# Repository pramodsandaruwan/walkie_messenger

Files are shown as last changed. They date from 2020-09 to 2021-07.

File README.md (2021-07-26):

# Walkie Messenger

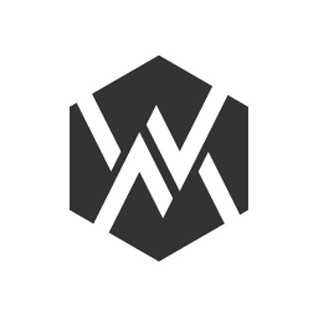
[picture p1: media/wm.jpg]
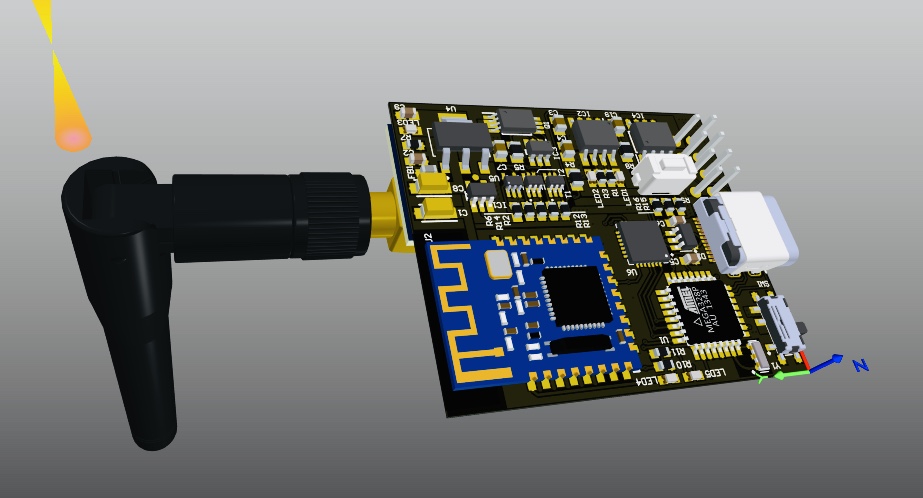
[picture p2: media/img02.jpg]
 

#### Title: Wireless Short-Range Communication Device (Walkie Messenger)
#### Introduction
A regular problem that can occur in hiking groups is that the group can easily spread out as the hike progresses. Some of your party will get chatting, some will stop to take photos, some are faster over rocky terrain or rock scrambles, some are simply fitter than others and can maintain a faster pace. Inevitably, a gap between the lead and whip of your group opens up and the main role of the group leader is to make sure that the gap doesn’t get so wide as to become unmanageable to the point where one part of the group can’t locate the other. Walkie Messenger is a solution for the above problem. It provides messaging, locating, tracking so you can stay connected to your group, whenever you're outside of cellular range. In case of a life-threatening emergency, the device can contact search & rescue services. (SOS function). This device comes with a mobile phone app (Android and IOS), so you can easily message your group members, send your GPS location, can track the friend’s location. In case of Low battery in your mobile, the device automatically sends your last location to all group members. In the SOS function, the device sends your GPS location to group members. if you are in cellular range, the device sends the location to search & rescue services through SMS. If not trying to send SMS through group members' mobile.

#### Product Description
##### Specifications

  - Wireless ranges
    - Wireless transmit and receive maximum range 1100m. (2.4GHz)
    - Bluetooth 5.0 with maximum range up to 100m.
    - Compatible with Bluetooth 4.2 and 4.0 devices.
  - Body
    - Dimensions 50(L) x 40(W) x 10(H) mm
    - Weight 180g
  - storage information
    - Work with mobile phone storage.
    - Device memory 32Kb (EEPROM).
  - Power
    - 2000mAH Li-Ion rechargeable nonremovable battery (3.7V).
    - Operating at 3.3V
    - Sleep mode while in standby
  - Charging
    - Recommended 1.5A USB charger for fast charging.
    
#### Functions
  - Control using mobile phone App.
  - Person to Person chat (Peer to peer communication).
  - Group chat capability (Mesh networking).
  - End to end encryption to chat.
  - Adjustable maximum transmitting range for power saving.
  - SOS button in the device to inform near persons in case of an emergency.
  - Low battery warning.
  - Firmware update over USB.
  - Automatic charging current controlling to match the power supply capability.
  - USB Type C reversible charging connector with charging current up to 1.2A.
  
#### Limitations
  - Battery life.
  - Wireless Transmitting range.
  - GPS coverage
  
#### Methodology
Walkie messenger used NRF24L01+ Single chip 2.4GHz Transceiver communicate between walkie devices (Maximum distance up to 1100m) and Bluetooth 5.0 used to connect to smart mobile phone (Maximum distance up to 100m). Some modern mobile phone has Bluetooth 4.0 or 4.2, So walkie can connect to these devices with maximum range 60m.

The amplifier IC and 20dB Antenna is used to increase the wireless communication Range. Bluetooth module has in-built PCB antenna. Atmega 328p 8bit microcontroller is used as controller.Microcontroller used UART (Universal Asynchronous Receiver/Transmitter) communication protocol to communicate with Bluetooth module and SPI (Serial peripheral interface) used to communicate between NRF24L01+ chip. 

The test message type and send to device using mobile phone application over Bluetooth. The GPS coordinates and mobile phone battery stats send to device automatically. NRF24L01+ chip has three power modes, so it can be configured using mobile app.

The CP2102n USB to Serial converter IC is used to connect device to USB interface. Firmware upgrading can do over USB (PC or MAC) and Bluetooth. Li-ion 300mAh is used to power the device, it works between the voltage level of 3.7v-4.2v and a BMS (Battery management system) is used to maintain battery health. A DC-DC converter is used to bring the voltage to 3.3V to power the Atmega 328p microcontroller and Communicating modules.

<center>
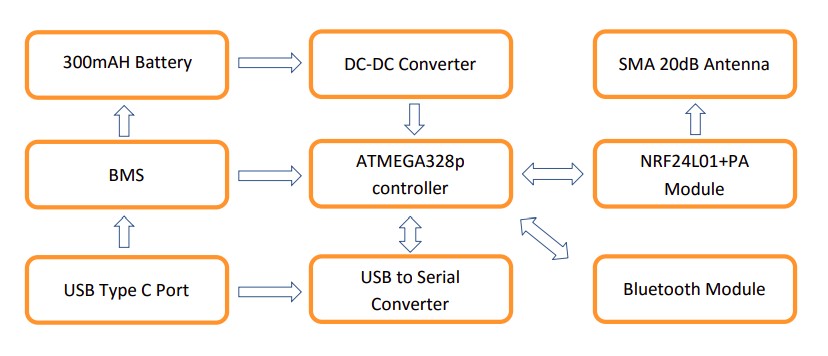
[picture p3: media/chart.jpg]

</center>

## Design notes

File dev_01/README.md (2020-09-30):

#### Walkie Messenger device 01 ( MINI version )

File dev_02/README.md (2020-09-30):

#### Walkie Messenger device 02 

##### Additional Specifications compared with WM mini 
- LCD display
- High Gain Antenna
- 2000mAH Li-ion Battery

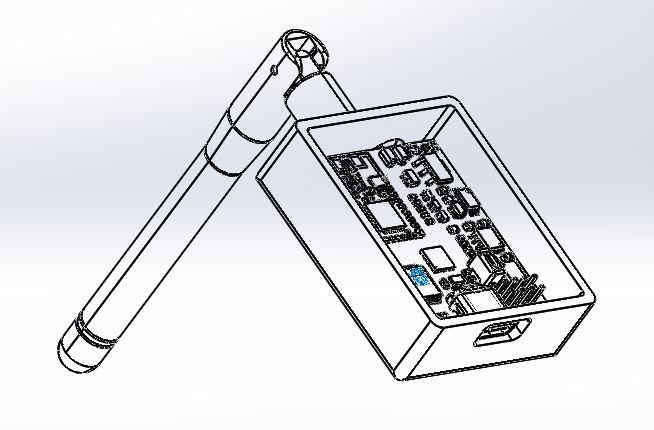
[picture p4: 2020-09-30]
media/Capture.JPG

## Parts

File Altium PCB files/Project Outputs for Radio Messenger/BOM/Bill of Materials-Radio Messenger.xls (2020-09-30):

Line # | Designator | value | Name | Description | Quantity | Manufacturer 1 | Manufacturer Part Number 1 | Manufacturer Lifecycle 1 | Supplier 1 | Supplier Part Number 1 | Supplier Unit Price 1 | Supplier Subtotal 1
 | C1, C8 | 10uF | tantalum capacitor 1206 | Capacitor Polarised | 2
 | C2, C5, C6, C9 | 0.1uF | capacitor 0603 | Capacitor | 4
 | C3, C4 | 10uF | 08055A101JAT2A | Capacitor | 2
 | C7 | 0.1uF | 08055A101JAT2A | Capacitor | 1
 | C19 | 4.7uF | 08055A101JAT2A | Capacitor | 1
 | D1 |  | USBLC6-2SC6 | USBLC6 Series 2 Line 6 V Uni / Bi-Directional ESD Protection - SOT-23-6 | 1
 | FB1 | 10uH | inductor 0603 | Ferrite Bead | 1
 | IC1 |  | TPS62203 | Integrated Circuit | 1
 | IC2 |  | TP4056 | Integrated Circuit | 1
 | IC3 |  | DW01-P | Integrated Circuit | 1
 | IC4 |  | SI4143DY-T1-GE3 | Integrated Circuit | 1
 | J1 |  | DX07S024XJ1R1100 | Cut Tape - Usb Type c Receptacle Mid Mnt Dual r | 1
 | J2 |  | S2B-ZR-SM4A-TF(LF)(SN) | Connector Header Surface Mount, Right Angle 2 position 0.059 _1.50mm_ | 1
 | LED1, LED4 | Red | HSMR-C191 | LED Indication - Discrete 3.4V 0603 _1608 Metric_ | 2
 | LED2, LED3 | Green | HSMR-C191 | LED Indication - Discrete 3.4V 0603 _1608 Metric_ | 2
 | LED5 | Orange | HSMR-C191 | LED Indication - Discrete 3.4V 0603 _1608 Metric_ | 1
 | Q1 |  | FS8205A | Transistor | 1
 | R1, R3, R7, R10, R11 | 1K | resistor | Resistor | 5
 | R2 | 1.2K | resistor | Resistor | 1
 | R4 | 100 | CPF0805 | Resistor | 1
 | R5 | 1K | CPF0805 | Resistor | 1
 | R6 | 470K | resistor | Resistor | 1
 | R8 | 10K | CPF0805 | Resistor | 1
 | R9, R12, R13 | 10K | resistor | Resistor | 3
 | R14 | 2K | resistor | Resistor | 1
 | R15 | 22.1K | resistor | Resistor | 1
 | R16 | 47.5K | resistor | Resistor | 1
 | S1 |  | PTS810SJK250SMTRLFS | Tactile Switch SPST-NO Top Actuated Surface Mount | 1
 | SW1 |  | 1437575-1 | Slide Switch SPDT Surface Mount, Right Angle | 1
 | T1, T2 |  | PMGD780SN | Mosfet Array 2 N-Channel _Dual_ 20V 1.2A 390mW Surface Mount 6-TSSOP | 2 | Philips | PMGD780SN,115 | Volume Production | Digi-Key | 1727-3127-1-ND | 0.42 | 0.84
 | U1 |  | ATMEGA328P-AN | AVR AVRÂ® ATmega Microcontroller IC 8-Bit 20MHz 32KB _16K x 16_ FLASH 32-TQFP _7x7_ | 1 | Microchip / Atmel | ATMEGA328P-ANR | Volume Production | Digi-Key | ATMEGA328P-ANRCT-ND | 2.18 | 2.18
 | U2 |  | JDY-23 | Bluetooth Bluetooth v4.0 Transceiver Module 2.4GHz Integrated, Chip Surface Mount | 1
 | U3 |  | NRF24L01P+ |  | 1
 | U4 |  | AMS1117 | 1A LOW DROPOUT VOLTAGE REGULATOR | 1 | STMicroelectronics | LD1117STR | Volume Production | Digi-Key | 497-1244-1-ND | 0.43 | 0.43
 | U5 |  | LMS33460MG | 3V Under Voltage Detector 5-SC70 -40 to 85 | 1
 | U6 |  | CP2102N-A01-GQFN28 | USB Bridge, USB to UART USB 2.0 UART Interface 28-QFN _5x5_ | 1
 | Y1 |  | PBRC8.00MR10X000 | 8MHz Ceramic Resonator Built in Capacitor 15pF Â±0.1% -40Â°C ~ 85Â°C Surface Mount | 1

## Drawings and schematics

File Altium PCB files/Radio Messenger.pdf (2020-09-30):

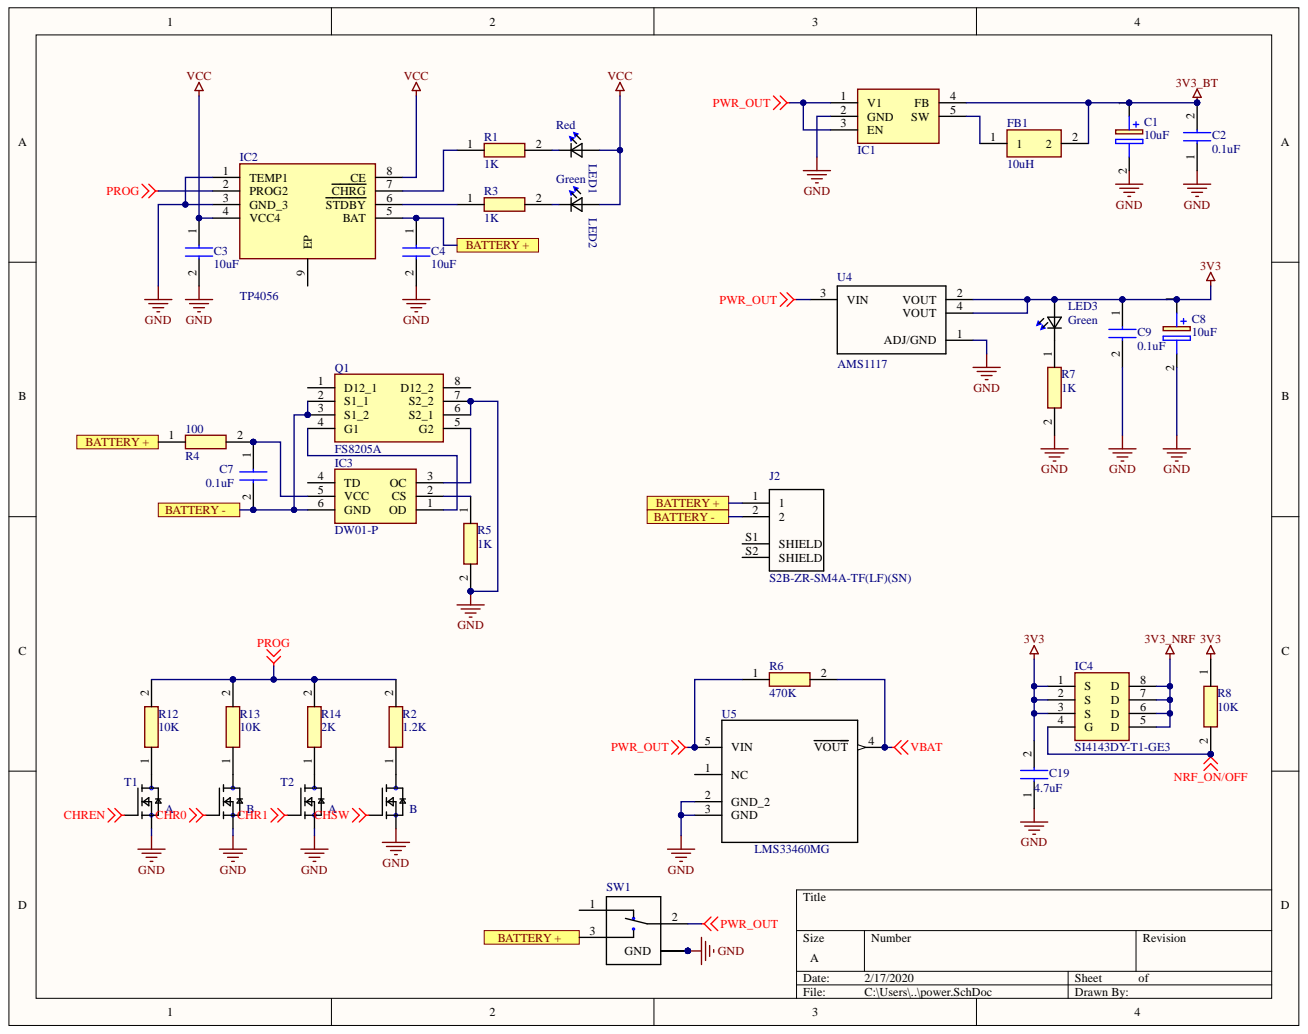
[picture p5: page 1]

PROG2 2

VCC4 4

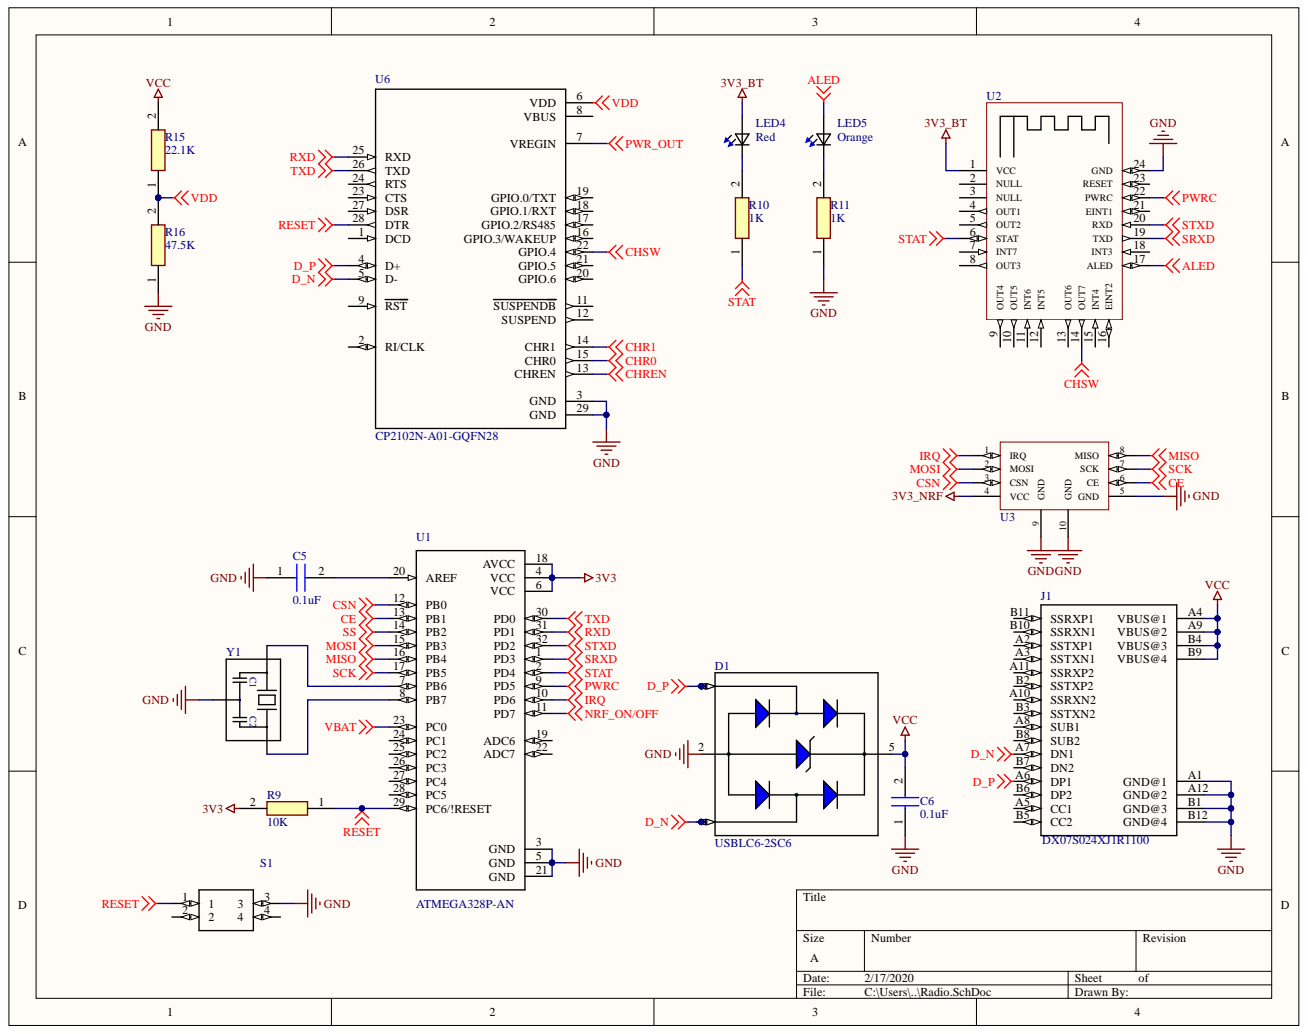
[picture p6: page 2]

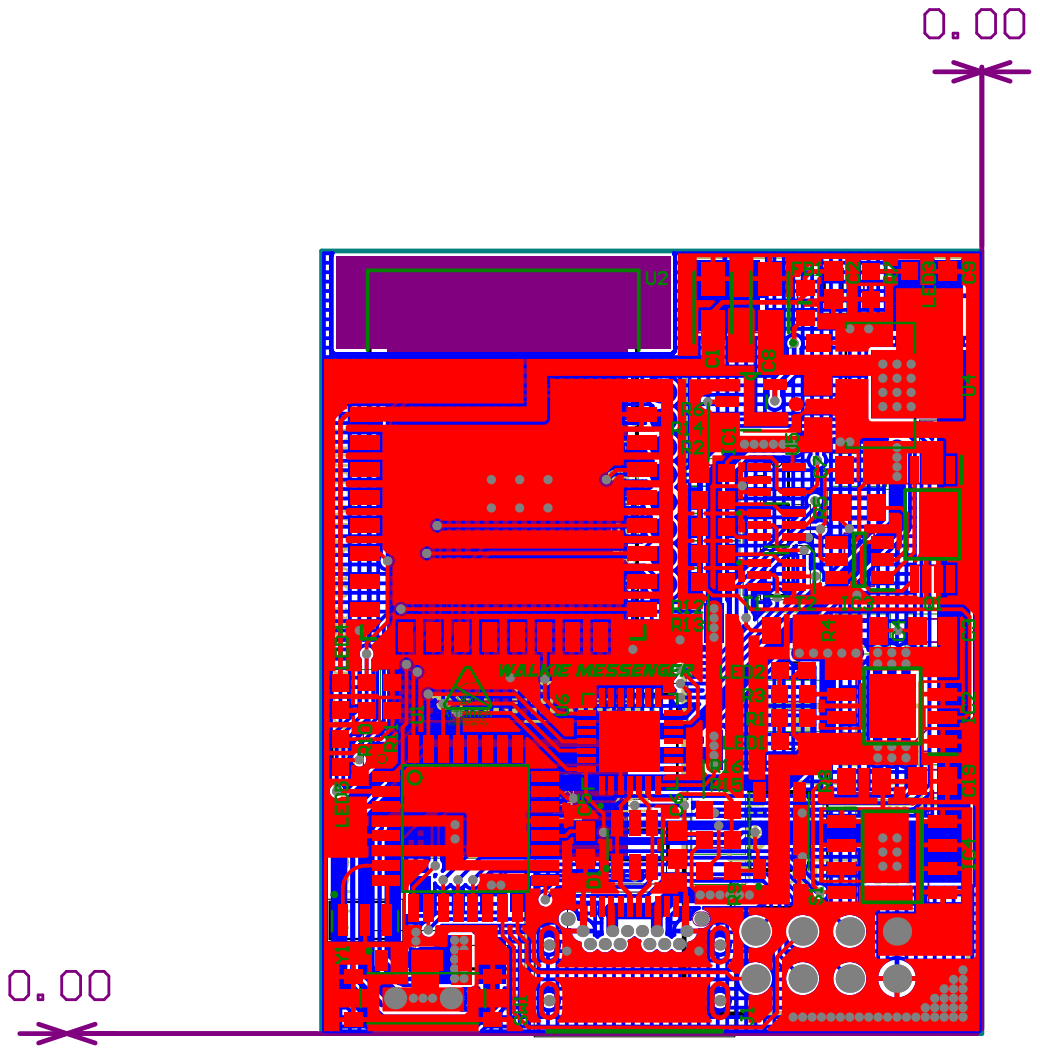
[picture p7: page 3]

Line # | Designator | value | Name | Description | Quantity | Footprint | Manufacturer 1 | Manufacturer PartNumber 1 | Manufacturer Lifecycle 1 | Supplier 1 | Supplier PartNumber 1 | Supplier UnitPrice 1 | Supplier Subtotal 1
| C1,C8 | 10uF | tantalum capacitor 1206 | Capacitor Polarised | 2 | CAPPM3216X180N | KEMET | T491A106K010AT | Volume Production | Digi-Key | 399-3684-1-ND | 0.41 | 0.82
| C2,C5,C6,C9 | 0.1uF | capacitor 0603 | Capacitor | 4 | *CAPC1608X95N | KEMET | C0603C104K5RACTU | Volume Production | Digi-Key | 399-5089-1-ND | 0.12 | 0.48
| C3,C4 | 10uF | 08055A101JAT2A | Capacitor | 2 | CAPC2012X94N | Kyocera AVX | 08055A101JAT2A | Volume Production | Digi-Key | 478-1316-1-ND | 0.16 | 0.32
| C7 | 0.1uF | 08055A101JAT2A | Capacitor | 1 | CAPC2012X94N | Kyocera AVX | 08055A101JAT2A | Volume Production | Digi-Key | 478-1316-1-ND | 0.16 | 0.16
| C19 | 4.7uF | 08055A101JAT2A | Capacitor | 1 | CAPC2012X94N | Kyocera AVX | 08055A101JAT2A | Volume Production | Newark | 60R6300 | 0.018 | 0.018
| D1 | | USBLC6-2SC6 | USBLC6 Series2 Line | 1 | *SOT95P2 80X145-6N
| FB1 | 10uH | inductor 0603 | Ferrite Bead | 1 | BEADC1608X95N
| IC1 | | TPS62203 | Integrated Circuit | 1 | SOT95P280X145-5N
| IC2 | | TP4056 | Integrated Circuit | 1 | SOIC127P600X175-9N
| IC3 | | DW01-P | Integrated Circuit | 1 | SOT95P280X135-6N
| IC4 | | SI4143DY-T1-GE3 | Integrated Circuit | 1 | SI4143DY-T1-GE3
| J1 | | DX07S024XJ1R1100 | CutTape - Usb Type c | 1 | *JAE_DX07 S024XJ1R1100_DX07S024XJ1R1100(Primary)
| J2 | | S2B-ZR-SM4A-TF(LF)(SN) | Connector Header Su | 1 | *JST_S2B-ZR-SM4A-TF(LF)(SN)_S2B-ZR-SM4A-TF(LF)(SN)(Primary)
| LED1, LED4 | Red | HSMR-C191 | LED Indication - Discr | 2 | *0603
| LED2, LED3 | Green | HSMR-C191 | LED Indication - Discr | 2 | *0603
| LED5 | Orange | HSMR-C191 | LED Indication - Discr | 1 | *0603
| Q1 | | FS8205A | Transistor | 1 | SOP65P640X120-8N
| R1,R3,R7,R10,R11 | 1K | resistor | Resistor | 5 | RESC1608X55N
| R2 | 1.2K | resistor | Resistor | 1 | RESC1608X55N
| R4 | 100 | CPF0805 | Resistor | 1 | RESC2012X65N
| R5 | 1K | CPF0805 | Resistor | 1 | RESC2012X65N
| R6 | 470K | resistor | Resistor | 1 | RESC1608X55N
| R8 | 10K | CPF0805 | Resistor | 1 | RESC2012X65N
| R9,R12,R13 | 10K | resistor | Resistor | 3 | RESC1608X55N
| R14 | 2K | resistor | Resistor | 1 | RESC1608X55N
| R15 | 22.1K | resistor | Resistor | 1 | RESC1608X55N
| R16 | 47.5K | resistor | Resistor | 1 | RESC1608X55N
| S1 | | PTS810SJK250SMTRLFS | Tactile Switch SPST-N | 1 | *PTS810SJG250SMTRLFS
| SW1 | | 1437575-1 | Slide Switch SPDTSur | 1 | *SW_MLL1200S_MLL1200S(Primary)
| T1,T2 | | PMGD780SN | MosfetArray2 N-Chan | 2 | *SOP65P210X110-6N | Philips | PMGD780SN,115 | Volume Production | Digi-Key | 1727-3127-1-ND | 0.42 | 0.84
| U1 | | ATMEGA328P-AN | AVRAVRÂ® ATmega M | 1 | *QF P80P900X900X120-32N | Microchip/Atmel | ATMEGA328P-ANR | Volume Production | Digi-Key | ATMEGA328P-ANRCT-ND | 2.18 | 2.18
| U2 | | JDY-23 | Bluetooth Bluetooth v | 1 | *JDY-23
| U3 | | NRF24L01P+ | | 1 | NRF24L01P+
| U4 | | AMS1117 | 1ALOWDROPOUTVOL | 1 | *SOT229P700X180-4N | STMicroelectronicsLD1117STR | | Volume Production | Digi-Key | 497-1244-1-ND | 0.43 | 0.43
| U5 | | LMS33460MG | 3VUnder Voltage Det | 1 | *SOT65P210X110-5N
| U6 | | CP2102N-A01-GQFN28 | USBBridge,USBto UA | 1 | *QFN50P500X500X80-29N
| Y1 | | PBRC8.00MR10X000 | 8MHzCeramicResona | 1 | *XTAL_PBRC8.00MR10X000

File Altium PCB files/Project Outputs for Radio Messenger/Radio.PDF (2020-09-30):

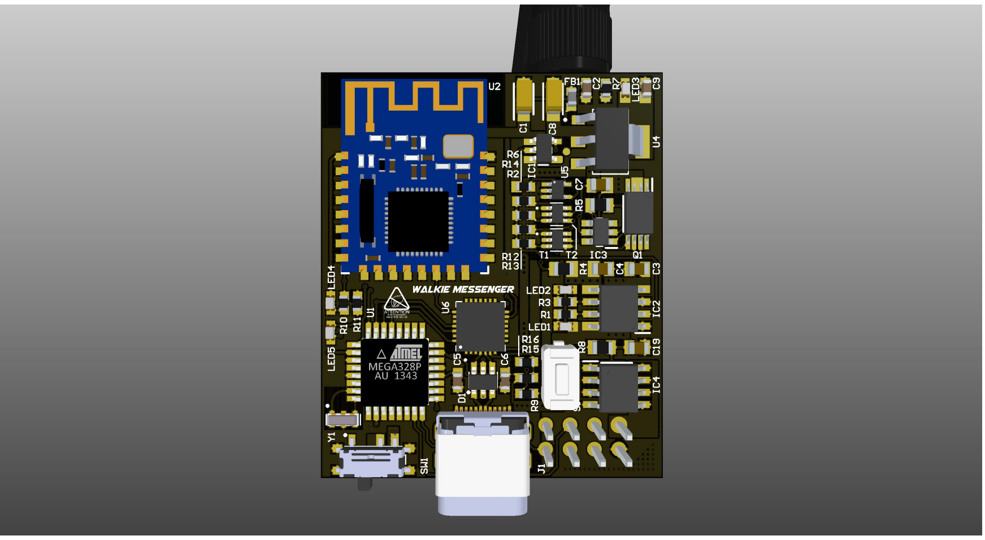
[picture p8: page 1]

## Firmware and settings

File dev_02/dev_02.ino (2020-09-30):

/************************************************************************************************
 * Devoloped by pramod sandaruwan for third year electric product design and manufacture course.
 * Contact: pramodsandaruwan80@gmail.com
 * Elelctrinic and Electronic Engineer
 * Undergraduate, University of peradeniya
************************************************************************************************/

/* Authors: Pramod Sandaruwan */

#include <SoftwareSerial.h>
#include <LiquidCrystal_I2C.h>
#include <string.h>
#include <EEPROM.h>

#include <RF24.h>
#include <RF24Network.h>
#include <SPI.h>

RF24 radio(7, 8);                // nRF24L01 (CE,CSN)
RF24Network network(radio);      // Include the radio in the network
const uint16_t this_node = 01;   // Address of this node in Octal format ( 04,031, etc)
const uint16_t node01 = 00; 

SoftwareSerial BlueTooth(2, 3); // RX, TX
LiquidCrystal_I2C lcd(0x27,20,4);  // set the LCD address to 0x27 for a 16 chars and 2 line display

bool bt_stat = 0;
const int red = 10;
const int grn = 9;
const int pwr = 6;
const int bt_pin = 4;
String a;
String CH_config;

void setup() {
  
  //Serial.begin(38400);
  lcd.init(); 
  pinMode(red, OUTPUT);
  pinMode(grn, OUTPUT);
  pinMode(pwr, OUTPUT);
  pinMode(bt_pin,INPUT);
  boot();                     
  BlueTooth.begin(38400);
  BlueTooth.println("bluetooth test ");
  
  SPI.begin();
  radio.begin();
  radio.setPALevel(RF24_PA_MAX);
  network.begin(EEPROMReadInt(128), this_node);  //(channel, node address)

  lcd.backlight();
  lcd.setCursor(0,0);
  lcd.print("Hello,welcome to");
  lcd.setCursor(0,1);
  lcd.print("Walkie messenger");
  delay(2000);
  lcd.setCursor(0,0);
  lcd.print("                ");
  lcd.setCursor(0,0);
  lcd.print("RF.CH>");
  lcd.setCursor(6,0);
  lcd.print(EEPROMReadInt(128));
  lcd.setCursor(8,0);
  lcd.print("|WM-V1.0");
}

void loop() {
  
  bt_connected();
  network.update();
  char text[] = "Walkie messenger data transfer";
  
  /* Bluetooth to RF */
  if(bt_connected()){
    if (BlueTooth.available() > 0) {
        // read the incoming byte:
        a = BlueTooth.readString();
        
        if (a.substring(0,5) == "setCH"){
          CH_config = a.substring(6,8);
          ch_configure(CH_config.toInt());
          }
        if (a == "getCH"){
          BlueTooth.print("RF_Channel = ");
          BlueTooth.println(EEPROMReadInt(128));
          return;
         }
    
        a.toCharArray(text, a.length()+1);
        
          RF24NetworkHeader header(node01);     // (Address where the data is going)
          bool ok = network.write(header, &text, sizeof(text)); // Send the data
          lcd_write("Msg sent");
          //Serial.println(ok);
        //Serial.println(text); //add rf sending fcn
        a = "";
      }
  } 
  /* RF to bluetooth */
  
    while ( network.available() ) {     // Is there any incoming data?
    RF24NetworkHeader header;
    char rtext[64] = "";
    network.read(header, &rtext, sizeof(rtext)); // Read the incoming data
    BlueTooth.println(rtext);
    lcd_write(rtext);
    //Serial.println(rtext);
    delay(200);
  }
}
void boot(){
  
  digitalWrite(red, HIGH);
  digitalWrite(grn, HIGH);
  digitalWrite(pwr, HIGH);
  delay(700);             
  digitalWrite(red, LOW);
  digitalWrite(grn, LOW);
  digitalWrite(pwr, LOW); 
  delay(300);
  digitalWrite(grn, HIGH);
  }
  
int bt_connected(){
  
  if(!digitalRead(bt_pin)){
    digitalWrite(pwr, HIGH-digitalRead(pwr)); 
    delay(200);
    bt_stat = 0;
    lcd.setCursor(0,1);
    lcd.print("BT-Not Connected");
    return 0;
    }
  digitalWrite(pwr, HIGH);
  if(bt_stat == 0){  
    lcd.setCursor(0,1);
    lcd.print("                ");
    lcd.setCursor(2,1);
    lcd.print("BT Connected");
    bt_stat = 1;
    }
  return 1;
  }
  
void lcd_write(char msg[64]){
  //lcd.clear();
  lcd.setCursor(0,1);
  lcd.print("                ");
  lcd.setCursor(0,1);
  lcd.print(msg);
  }

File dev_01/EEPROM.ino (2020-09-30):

/* functions */
void(* resetFunc) (void) = 0;

void ch_configure(int channelNo){

      EEPROMWriteInt(128,channelNo);
      BlueTooth.println("Channel set to "+CH_config);
      BlueTooth.println("Restarting device...");
      delay(1000);
      resetFunc(); // call reset function
      while(1);    // never gets here. NOT NEEDED OF COURSE
   }
 
void EEPROMWriteInt(int address, int value) {

      byte two = (value & 0xFF);
      byte one = ((value >> 8) & 0xFF);
      
      EEPROM.update(address, two);
      EEPROM.update(address + 1, one);
  }
   
int EEPROMReadInt(int address) {

      long two = EEPROM.read(address);
      long one = EEPROM.read(address + 1);
   
      return ((two << 0) & 0xFFFFFF) + ((one << 8) & 0xFFFFFFFF);
  }
